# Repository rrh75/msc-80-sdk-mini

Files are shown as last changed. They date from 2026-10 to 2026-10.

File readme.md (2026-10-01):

# MSC-80 mini 8080A single board computer
This is a modified version of old Intel MSC-80 SDK, which utilize the Intel 8080A 8-bit processor. In this modification I tried to reduce size of pcb and number of ICs to minimum.

I have a bunch of old soviet era 8080 CPU clones, which are relatively chip now.
In current revision 74LS93 divider was replaces by 74LS92 divider, with is naturally /12, /6 or /3 divider. The board on picture below shows previous version with /16 divider (КР1553ИЕ5), configurated as /6.

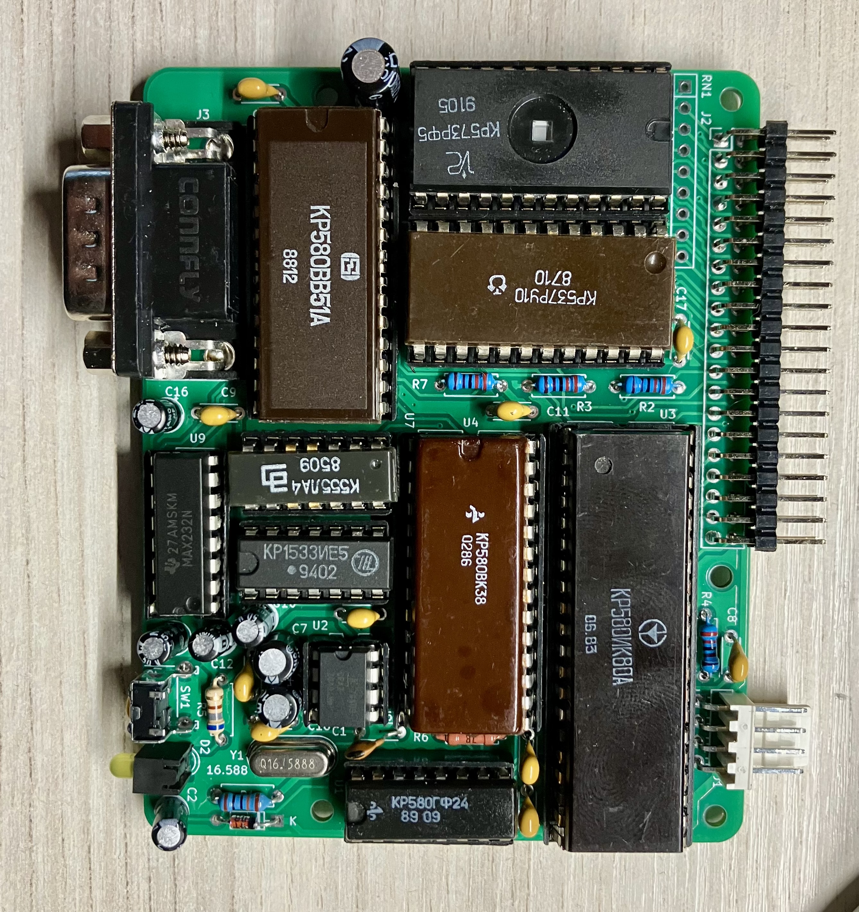
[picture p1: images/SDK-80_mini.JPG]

The board has 2KB of UV EEPROM, 2KB of SRAM and 8251 UART controller for communication with console. In this version I used a 16,588MHz crystal to get the 1,8432MHz clock output, which could be divided by 6 or by 12 ro get correct baudrates.
Adress decoding also simplified comparing to original design and done by 3NAND gates. The address map are follow:
* ROM: 0000H-07FFH
* RAM: 1000H-17FFH
* UART: 0FAH
  
This version of board does not provide address buffering, but it is enough to work with onboard chips.
Communication with terminal program on the host computer is done via com port. Depending of the software and divide ratio it could be up to 19200 kb/s, RTS/CTS handshake, 8n1.

Since the processor use three voltages to operate, the board has build-in -5V charge pump circuit, but still required +5V and +12V. I used simple step-up converter to get +12V from +5V, but it was mounted outside the board. Power consumption from +5V is about 600 mA.
# Software
I've tried this board with original firmware, but since it was very old and intended to work with teletype, original monitor have very limited set of commands.
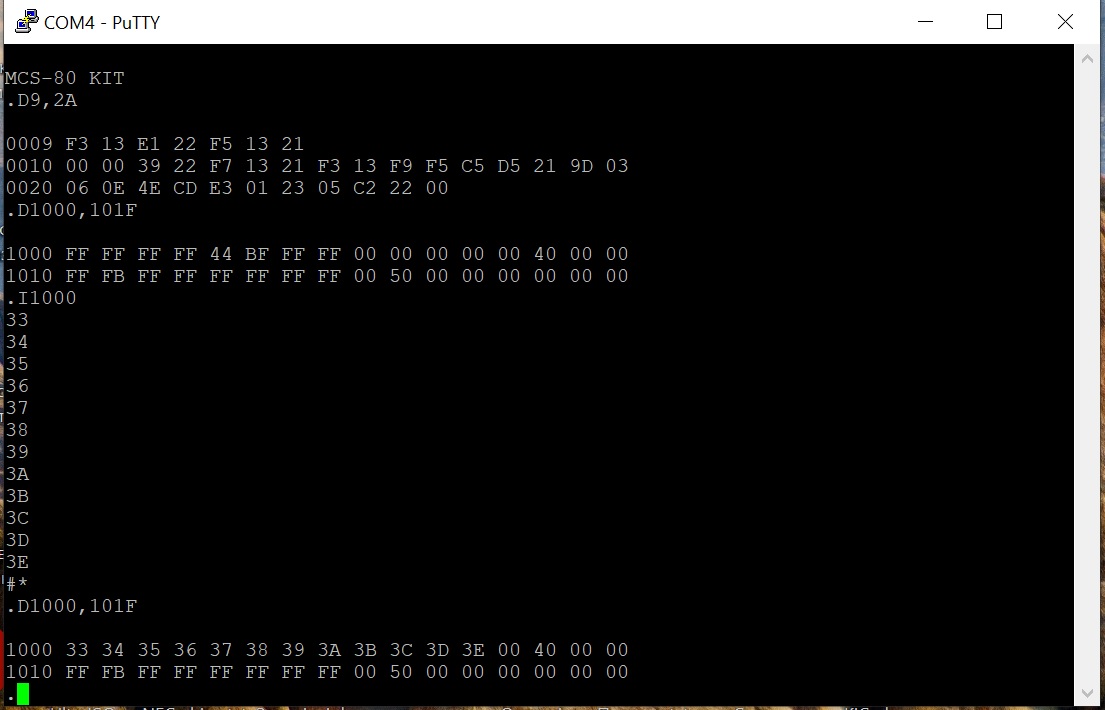
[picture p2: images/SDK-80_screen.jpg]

I found nice solution with GW monitor, with small modifications of addresses in source code it is also work and feet in existing ROM.

There also simple test program to test the 8251 communication functions.
Also I want to try 1K BASIC on this board.

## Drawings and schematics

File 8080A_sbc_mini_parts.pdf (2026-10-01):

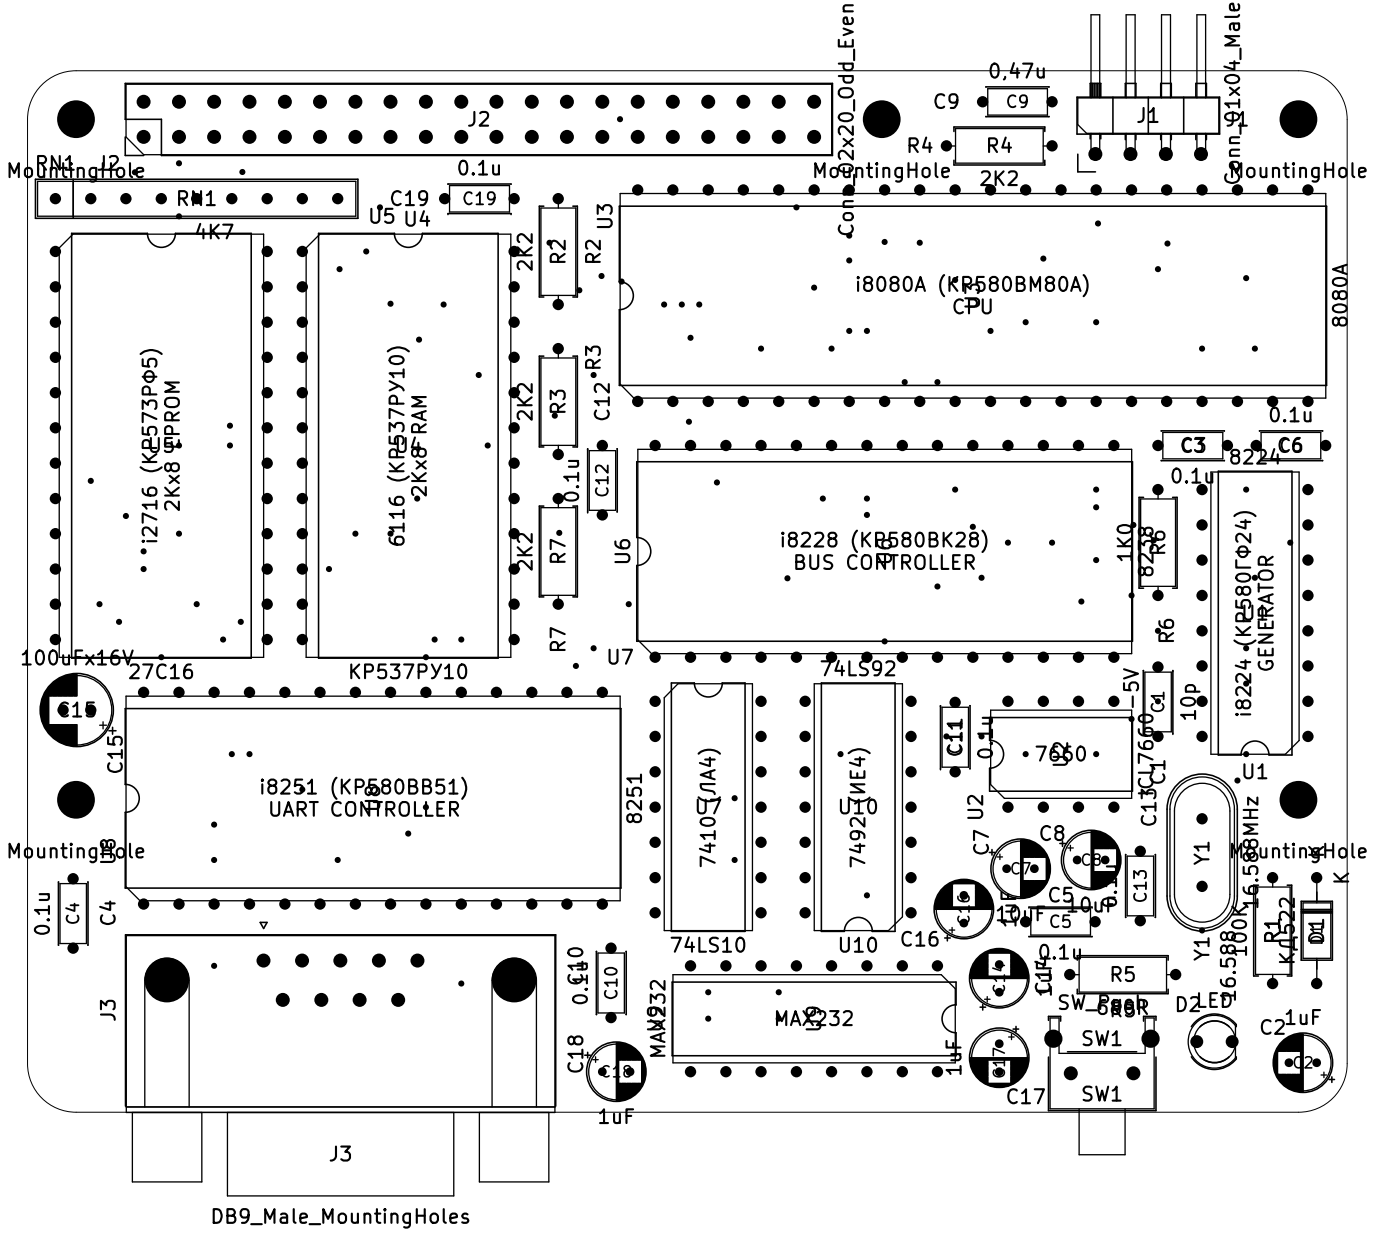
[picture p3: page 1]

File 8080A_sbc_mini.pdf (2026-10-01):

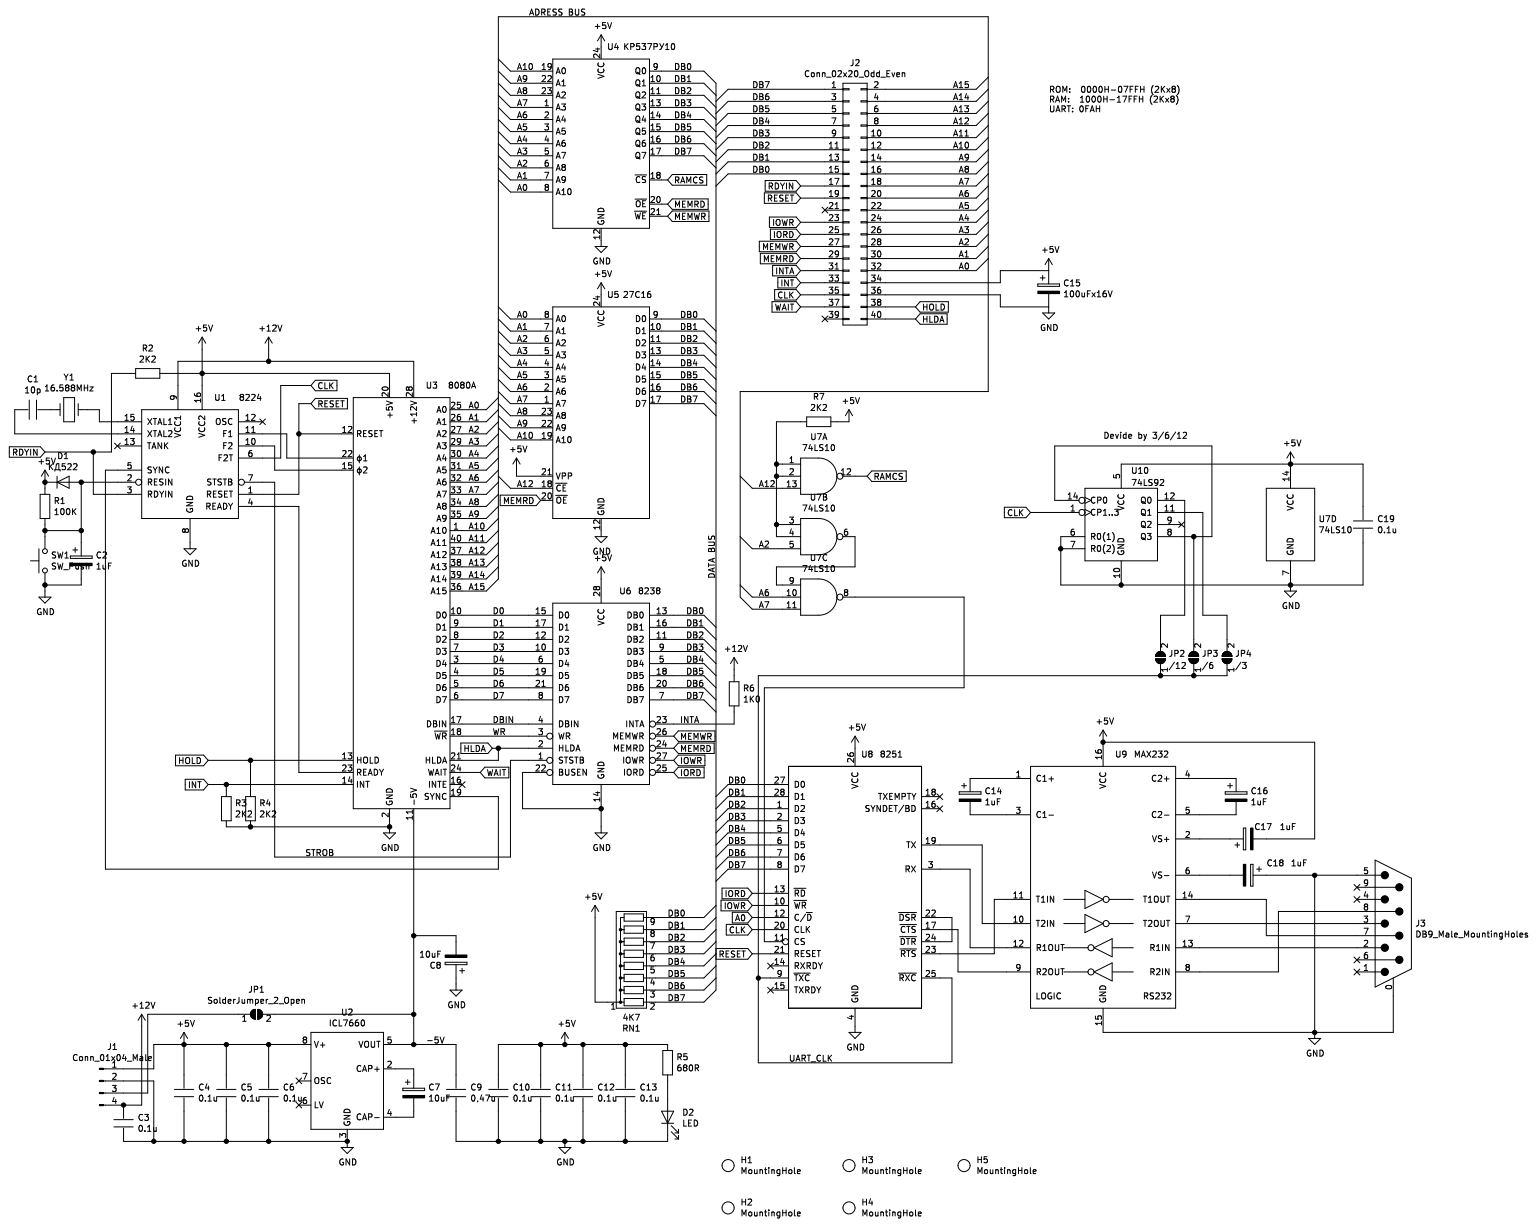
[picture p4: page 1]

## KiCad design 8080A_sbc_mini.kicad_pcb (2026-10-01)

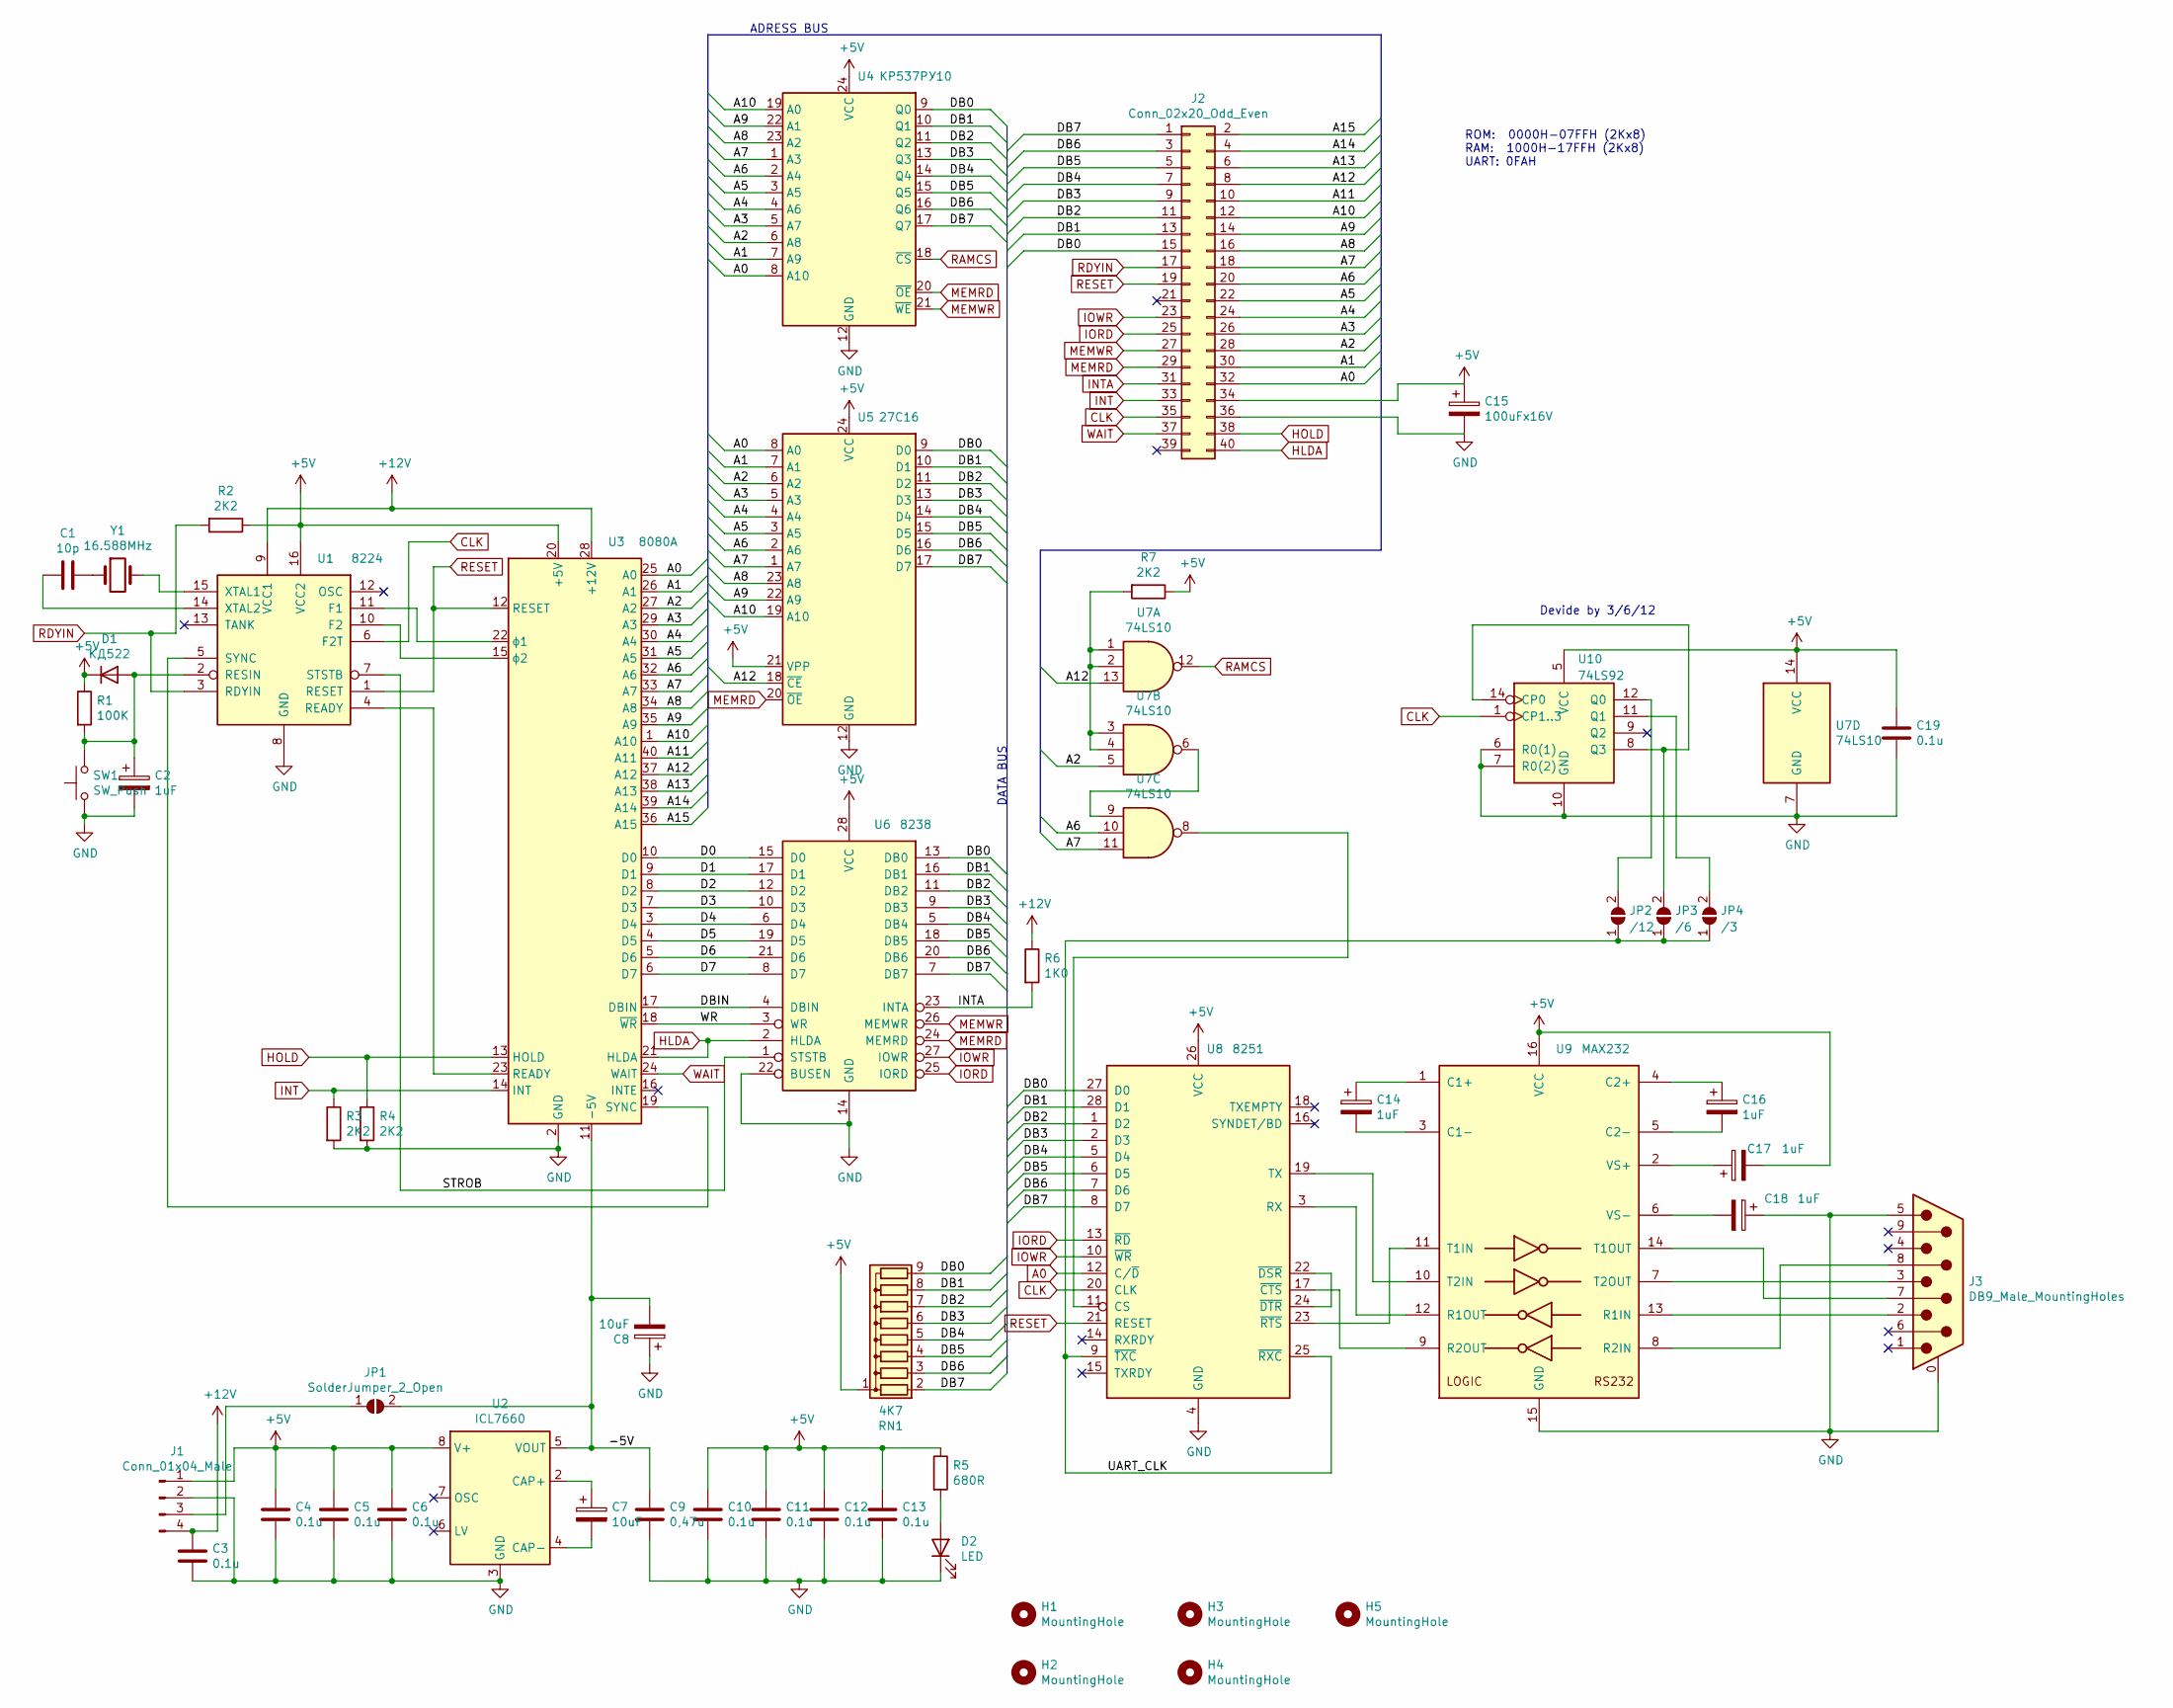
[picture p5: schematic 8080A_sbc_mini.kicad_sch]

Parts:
C1: 10p; C_Disc_D4.3mm_W1.9mm_P5.00mm
C2, C14, C16, C17, C18: 1uF; CP_Radial_D4.0mm_P2.00mm
C3, C4, C5, C6, C10, C11, C12, C13, C19: 0.1u; C_Disc_D4.3mm_W1.9mm_P5.00mm
C7, C8: 10uF; CP_Radial_D4.0mm_P2.00mm
C9: 0,47u; C_Disc_D4.3mm_W1.9mm_P5.00mm
C15: 100uFx16V; CP_Radial_D5.0mm_P2.00mm
D1: КД522; D_DO-35_SOD27_P7.62mm_Horizontal
D2: LED; LED_D3.0mm
H1, H2, H3, H4, H5: MountingHole; MountingHole_2.7mm_M2.5
J1: Conn_01x04_Male; Pin_Header_Angled_1x04_Pitch2.54mm
J2: Conn_02x20_Odd_Even; Pin_Header_Straight_2x20_Pitch2.54mm
J3: DB9_Male_MountingHoles; DSUB-9_Male_Horizontal_P2.77x2.84mm_EdgePinOffset7.70mm_Hou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
JP1: SolderJumper_2_Open; SolderJumper-2_P1.3mm_Open_RoundedPad1.0x1.5mm
JP2: /12; SolderJumper-2_P1.3mm_Open_RoundedPad1.0x1.5mm
JP3: /6; SolderJumper-2_P1.3mm_Open_RoundedPad1.0x1.5mm
JP4: /3; SolderJumper-2_P1.3mm_Open_RoundedPad1.0x1.5mm
R1: 100K; R_Axial_DIN0207_L6.3mm_D2.5mm_P7.62mm_Horizontal
R2, R3, R4, R7: 2K2; R_Axial_DIN0207_L6.3mm_D2.5mm_P7.62mm_Horizontal
R5: 680R; R_Axial_DIN0207_L6.3mm_D2.5mm_P7.62mm_Horizontal
R6: 1K0; R_Axial_DIN0207_L6.3mm_D2.5mm_P7.62mm_Horizontal
RN1: 4K7; R_Array_SIP9
SW1: SW_Push; SW_Tactile_SKHH_Angled
U1: 8224; DIP-16_W7.62mm
U2: ICL7660; DIP-8_W7.62mm
U3: 8080A; DIP-40_W15.24mm
U4: КР537РУ10; DIP-24_W15.24mm
U5: 27C16; DIP-24_W15.24mm
U6: 8238; DIP-28_W15.24mm
U7: 74LS10
U8: 8251; DIP-28_W15.24mm
U9: MAX232; DIP-16_W7.62mm
U10: 74LS92; DIP-14_W7.62mm
Y1: 16.588MHz; Crystal_HC49-U_Vertical

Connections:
+5V: C4.1, C5.1, C6.1, C10.1, C11.1, C12.1, C13.1, C15.1, C17.2, C19.1, D1.1 (K), J1.1, J2.34, R1.1, R2.1, R5.1, R7.1, RN1.1 (common), U1.16 (VCC2), U2.8 (V+), U3.20 (+5V), U4.24 (VCC), U5.21 (VPP), U5.24 (VCC), U6.28 (VCC), U7.14 (VCC), U8.26 (VCC), U9.16 (VCC), U10.5 (VCC)
+12V: C3.1, J1.4, R6.1, U1.9 (VCC1), U3.28 (+12V)
/-5V: C8.2, C9.1, JP1.2 (B), U2.5 (VOUT), U3.11 (-5V)
/A1: J2.30, U3.26 (A1), U4.7 (A9), U5.7 (A1)
/A2: J2.28, U3.27 (A2), U4.6 (A8), U5.6 (A2), U7.5
/A3: J2.26, U3.29 (A3), U4.5 (A7), U5.5 (A3)
/A4: J2.24, U3.30 (A4), U4.4 (A6), U5.4 (A4)
/A5: J2.22, U3.31 (A5), U4.3 (A5), U5.3 (A5)
/A6: J2.20, U3.32 (A6), U4.2 (A4), U5.2 (A6), U7.10
/A7: J2.18, U3.33 (A7), U4.1 (A3), U5.1 (A7), U7.11
/A8: J2.16, U3.34 (A8), U4.23 (A2), U5.23 (A8)
/A9: J2.14, U3.35 (A9), U4.22 (A1), U5.22 (A9)
/A10: J2.12, U3.1 (A10), U4.19 (A0), U5.19 (A10)
/A11: J2.10, U3.40 (A11)
/A12: J2.8, U3.37 (A12), U5.18 (~CE), U7.13
/A13: J2.6, U3.38 (A13)
/A14: J2.4, U3.39 (A14)
/A15: J2.2, U3.36 (A15)
/D0: U3.10 (D0), U6.15 (D0)
/D1: U3.9 (D1), U6.17 (D1)
/D2: U3.8 (D2), U6.12 (D2)
/D3: U3.7 (D3), U6.10 (D3)
/D4: U3.3 (D4), U6.6 (D4)
/D5: U3.4 (D5), U6.19 (D5)
/D6: U3.5 (D6), U6.21 (D6)
/D7: U3.6 (D7), U6.8 (D7)
/DB0: J2.15, RN1.9 (R8), U4.9 (Q0), U5.9 (D0), U6.13 (DB0), U8.27 (D0)
/DB1: J2.13, RN1.8 (R7), U4.10 (Q1), U5.10 (D1), U6.16 (DB1), U8.28 (D1)
/DB2: J2.11, RN1.7 (R6), U4.11 (Q2), U5.11 (D2), U6.11 (DB2), U8.1 (D2)
/DB3: J2.9, RN1.6 (R5), U4.13 (Q3), U5.13 (D3), U6.9 (DB3), U8.2 (D3)
/DB4: J2.7, RN1.5 (R4), U4.14 (Q4), U5.14 (D4), U6.5 (DB4), U8.5 (D4)
/DB5: J2.5, RN1.4 (R3), U4.15 (Q5), U5.15 (D5), U6.18 (DB5), U8.6 (D5)
/DB6: J2.3, RN1.3 (R2), U4.16 (Q6), U5.16 (D6), U6.20 (DB6), U8.7 (D6)
/DB7: J2.1, RN1.2 (R1), U4.17 (Q7), U5.17 (D7), U6.7 (DB7), U8.8 (D7)
/DBIN: U3.17 (DBIN), U6.4 (DBIN)
/STROB: U1.7 (STSTB), U6.1 (STSTB)
/UART_CLK: JP2.1 (A), JP3.1 (A), JP4.1 (A), U8.9 (~TXC), U8.25 (~RXC)
/WR: U3.18 (~WR), U6.3 (WR)
A0: J2.32, U3.25 (A0), U4.8 (A10), U5.8 (A0), U8.12 (C/~D)
CLK: J2.35, U1.6 (F2T), U8.20 (CLK), U10.1 (CP1..3)
GND: C2.2, C3.2, C4.2, C5.2, C6.2, C8.1, C9.2, C10.2, C11.2, C12.2, C13.2, C15.2, C18.1, C19.2, D2.1 (K), J1.2, J2.36, J3.0 (PAD), J3.5, R3.2, R4.2, SW1.1, U1.8 (GND), U2.3 (GND), U3.2 (GND), U4.12 (GND), U5.12 (GND), U6.14 (GND), U6.22 (BUSEN), U7.7 (GND), U8.4 (GND), U9.15 (GND), U10.6 (R0(1)), U10.7 (R0(2)), U10.10 (GND)
HLDA: J2.40, U3.21 (HLDA), U6.2 (HLDA)
HOLD: J2.38, R4.1, U3.13 (HOLD)
INT: J2.33, R3.1, U3.14 (INT)
INTA: J2.31, R6.2, U6.23 (INTA)
IORD: J2.25, U6.25 (IORD), U8.13 (~RD)
IOWR: J2.23, U6.27 (IOWR), U8.10 (~WR)
MEMRD: J2.29, U4.20 (~OE), U5.20 (~OE), U6.24 (MEMRD)
MEMWR: J2.27, U4.21 (~WE), U6.26 (MEMWR)
unnamed: C1.1, Y1.1
unnamed: C1.2, U1.14 (XTAL2)
unnamed: C2.1, D1.2 (A), R1.2, SW1.2, U1.2 (RESIN)
unnamed: C7.1, U2.2 (CAP+)
unnamed: C7.2, U2.4 (CAP-)
unnamed: C14.1, U9.1 (C1+)
unnamed: C14.2, U9.3 (C1-)
unnamed: C16.1, U9.4 (C2+)
unnamed: C16.2, U9.5 (C2-)
unnamed: C17.1, U9.2 (VS+)
unnamed: C18.2, U9.6 (VS-)
unnamed: D2.2 (A), R5.2
unnamed: J1.3, JP1.1 (A)
unnamed: J3.2, U9.13 (R1IN)
unnamed: J3.3, U9.7 (T2OUT)
unnamed: J3.7, U9.14 (T1OUT)
unnamed: J3.8, U9.8 (R2IN)
unnamed: JP2.2 (B), U10.12 (Q0)
unnamed: JP3.2 (B), U10.8 (Q3), U10.14 (CP0)
unnamed: JP4.2 (B), U10.11 (Q1)
unnamed: R7.2, U7.1, U7.2, U7.3, U7.4
unnamed: U1.4 (READY), U3.23 (READY)
unnamed: U1.5 (SYNC), U3.19 (SYNC)
unnamed: U1.10 (F2), U3.15 (ϕ2)
unnamed: U1.11 (F1), U3.22 (ϕ1)
unnamed: U1.15 (XTAL1), Y1.2
unnamed: U7.6, U7.9
unnamed: U7.8, U8.11 (CS)
unnamed: U8.3 (RX), U9.12 (R1OUT)
unnamed: U8.17 (~CTS), U9.9 (R2OUT)
unnamed: U8.19 (TX), U9.10 (T2IN)
unnamed: U8.22 (~DSR), U8.24 (~DTR)
unnamed: U8.23 (~RTS), U9.11 (T1IN)
RAMCS: U4.18 (~CS), U7.12
RDYIN: J2.17, R2.2, U1.3 (RDYIN)
RESET: J2.19, U1.1 (RESET), U3.12 (RESET), U8.21 (RESET)
WAIT: J2.37, U3.24 (WAIT)

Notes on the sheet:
ROM: 0000H-07FFH (2Kx8) RAM: 1000H-17FFH (2Kx8) UART: 0FAH
Devide by 3/6/12
DATA BUS
ADRESS BUS

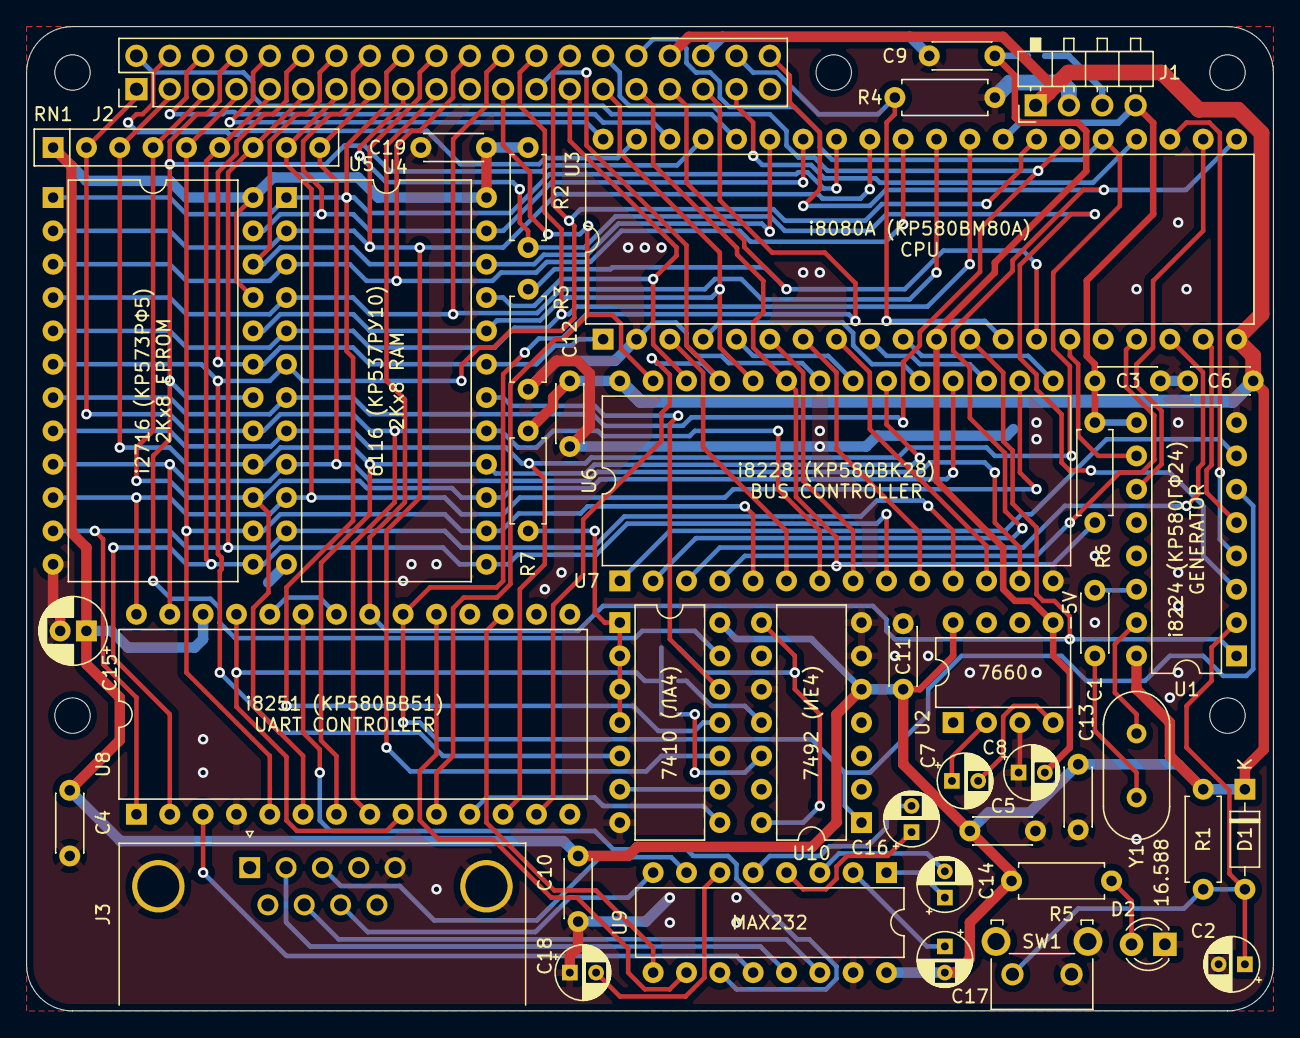
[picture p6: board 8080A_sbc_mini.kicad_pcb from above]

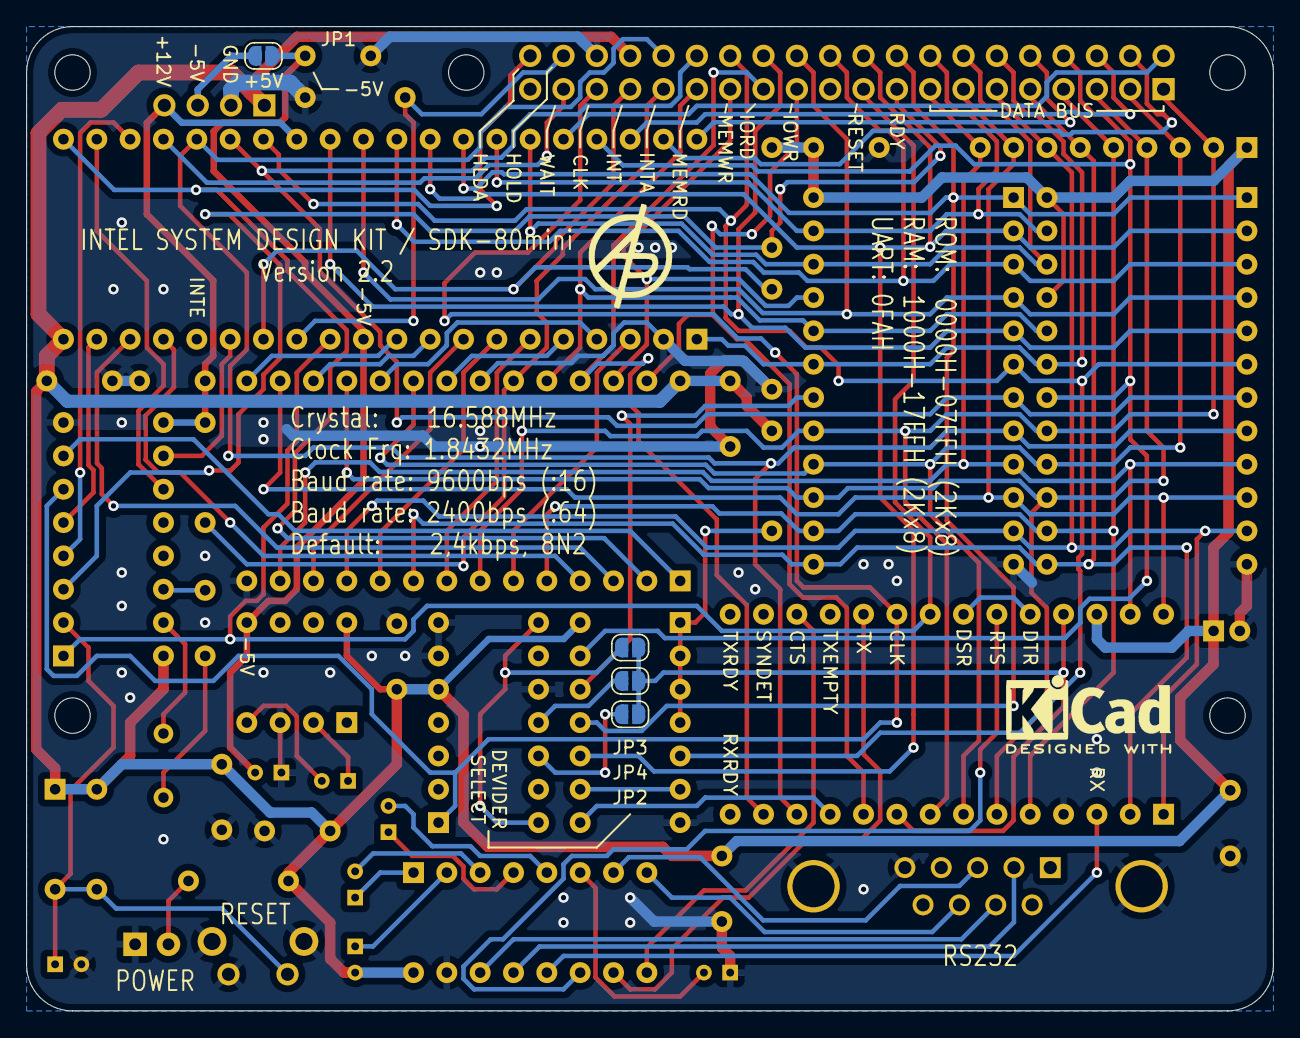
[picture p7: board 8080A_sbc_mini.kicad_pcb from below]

Board: 2 copper layers, 95.0 x 75.0 mm, 53 parts (4 on the bottom side), 86 nets.
